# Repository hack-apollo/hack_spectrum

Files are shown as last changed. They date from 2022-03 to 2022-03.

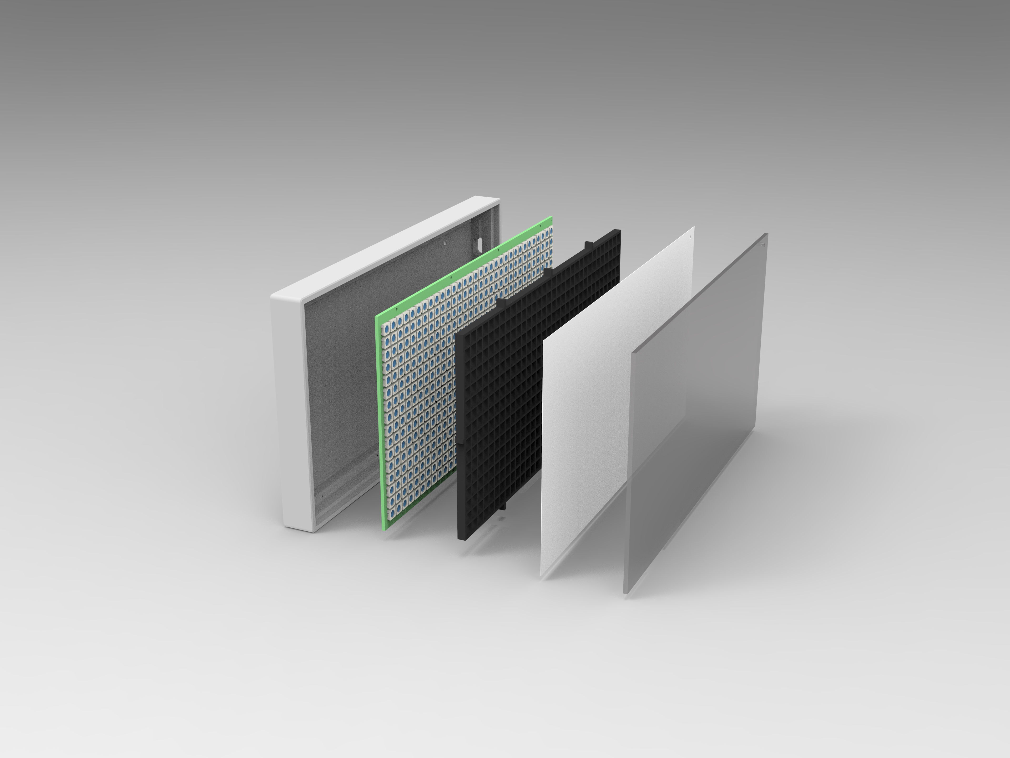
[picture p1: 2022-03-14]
3D/渲染图.jpg

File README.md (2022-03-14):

Hack Labs Audio Spectrum ：https://www.youtube.com/watch?v=lrZFiLHbFRo&lc=Ugw5ZR2V5kvy2mBF6H14AaABAg                                                                                
Author: HACK实验室                                                                                     
YouTube ID: HACK实验室, welcome to subscribe https://www.youtube.com/channel/UCxFY1FcIYK9d7riTvIh6eiA                                                         
Hack Audio Spectrum is a free download and may be used, modified, evaluated and
distributed without charge provided the user adheres to version three of the GNU
General Public License (GPL) and does not remove the copyright notice or this
text.  The GPL V3 text is available on the gnu.org web site
作者：HACK实验室                                                                                        
B站ID：HACK实验室  欢迎订阅 https://space.bilibili.com/395145107                                                                            
微信公众号：HACK实验室，开源资料唯一发布点，定期分享开源硬件以及有价值的技术文章，欢迎关注.

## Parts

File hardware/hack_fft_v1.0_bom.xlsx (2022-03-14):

编号 | 名称 | 值 | 封装 | 数量 | 备注
R1,R4,R5 |  | 100Ω | 0603_R | 3
R2,R3,R10,R11 |  | 5.1KΩ | 0603_R | 4
R6,R7,R8 |  | 10KΩ | 0603_R | 3
R9 |  | 100KΩ | 0603_R | 1
C1,C2,C3,C4,C8,C10,C101&C410 | X5R | 1uF/50V | 0603_C | 64
C5,C6,C9 | X7R | 0.1uF/50V | 0603_C | 3
C7 | 钽电容 | 10uF/16V | A型 3216 | 1
D1~D512 | WS2812B-3535 |  |  | 512
D0,DD0 | 肖特基二极管 | 1N5819WS | SOD-323 | 2
Q1 | BC847BS |  | SOT-363 | 1
U1 | ESP32-PICO-D4 |  | QFN-48 | 1
U2 | ICS-43434 |  | LGA-CAV-6 | 1
U3 | CH340C |  | SOP-16 | 1
U4 | SPX3819M5-L-3-3 |  | SOT23-5 | 1
A1 | PRO-OB-440 | 2.4G射频天线
SW1 | 轻触开关 | 高8mm | 4*4*8MM | 1 | 关键字“4*4*8MM”
P1 | USB-Type-C母座 | SMT全贴片式 16P |  | 1 | 关键字“USB3.1 Type-C 母座 SMT全贴片式 16P”
P2 | USB-Type-C母座 | Type-C 6P 立式贴片6.8mm |  | 1 | 关键字“Type-C母座6P 立式贴片6.8mm”
P6 x8 | 圆头自攻螺丝十字 | M1.4*6 |  | 8
如果整理有误还望见谅，可到“HACK实验室”微信公众号私信通知修改，谢谢！

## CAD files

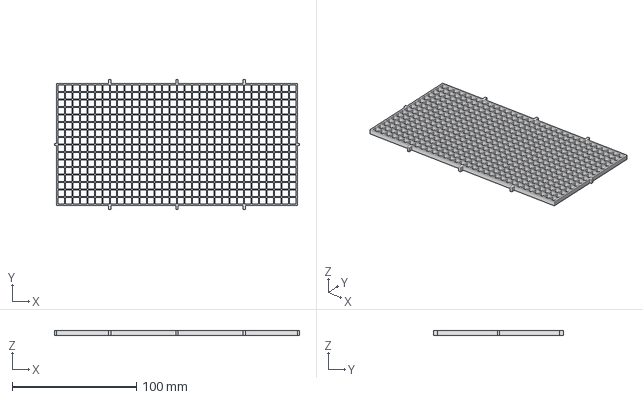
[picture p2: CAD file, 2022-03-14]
3D/stp/栅格.stp
196.8 x 104.8 x 4.00 mm

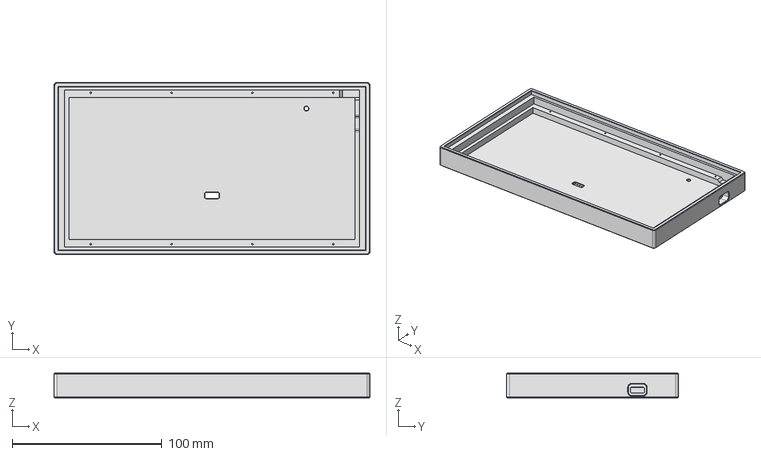
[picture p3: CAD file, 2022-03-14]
3D/stp/壳体.stp
211.0 x 115.0 x 16.5 mm

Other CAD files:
3D/扩散板.dwg
3D/滤光板(厚度2mm).dwg
3D/stl/壳体.stl
3D/stl/栅格.stl

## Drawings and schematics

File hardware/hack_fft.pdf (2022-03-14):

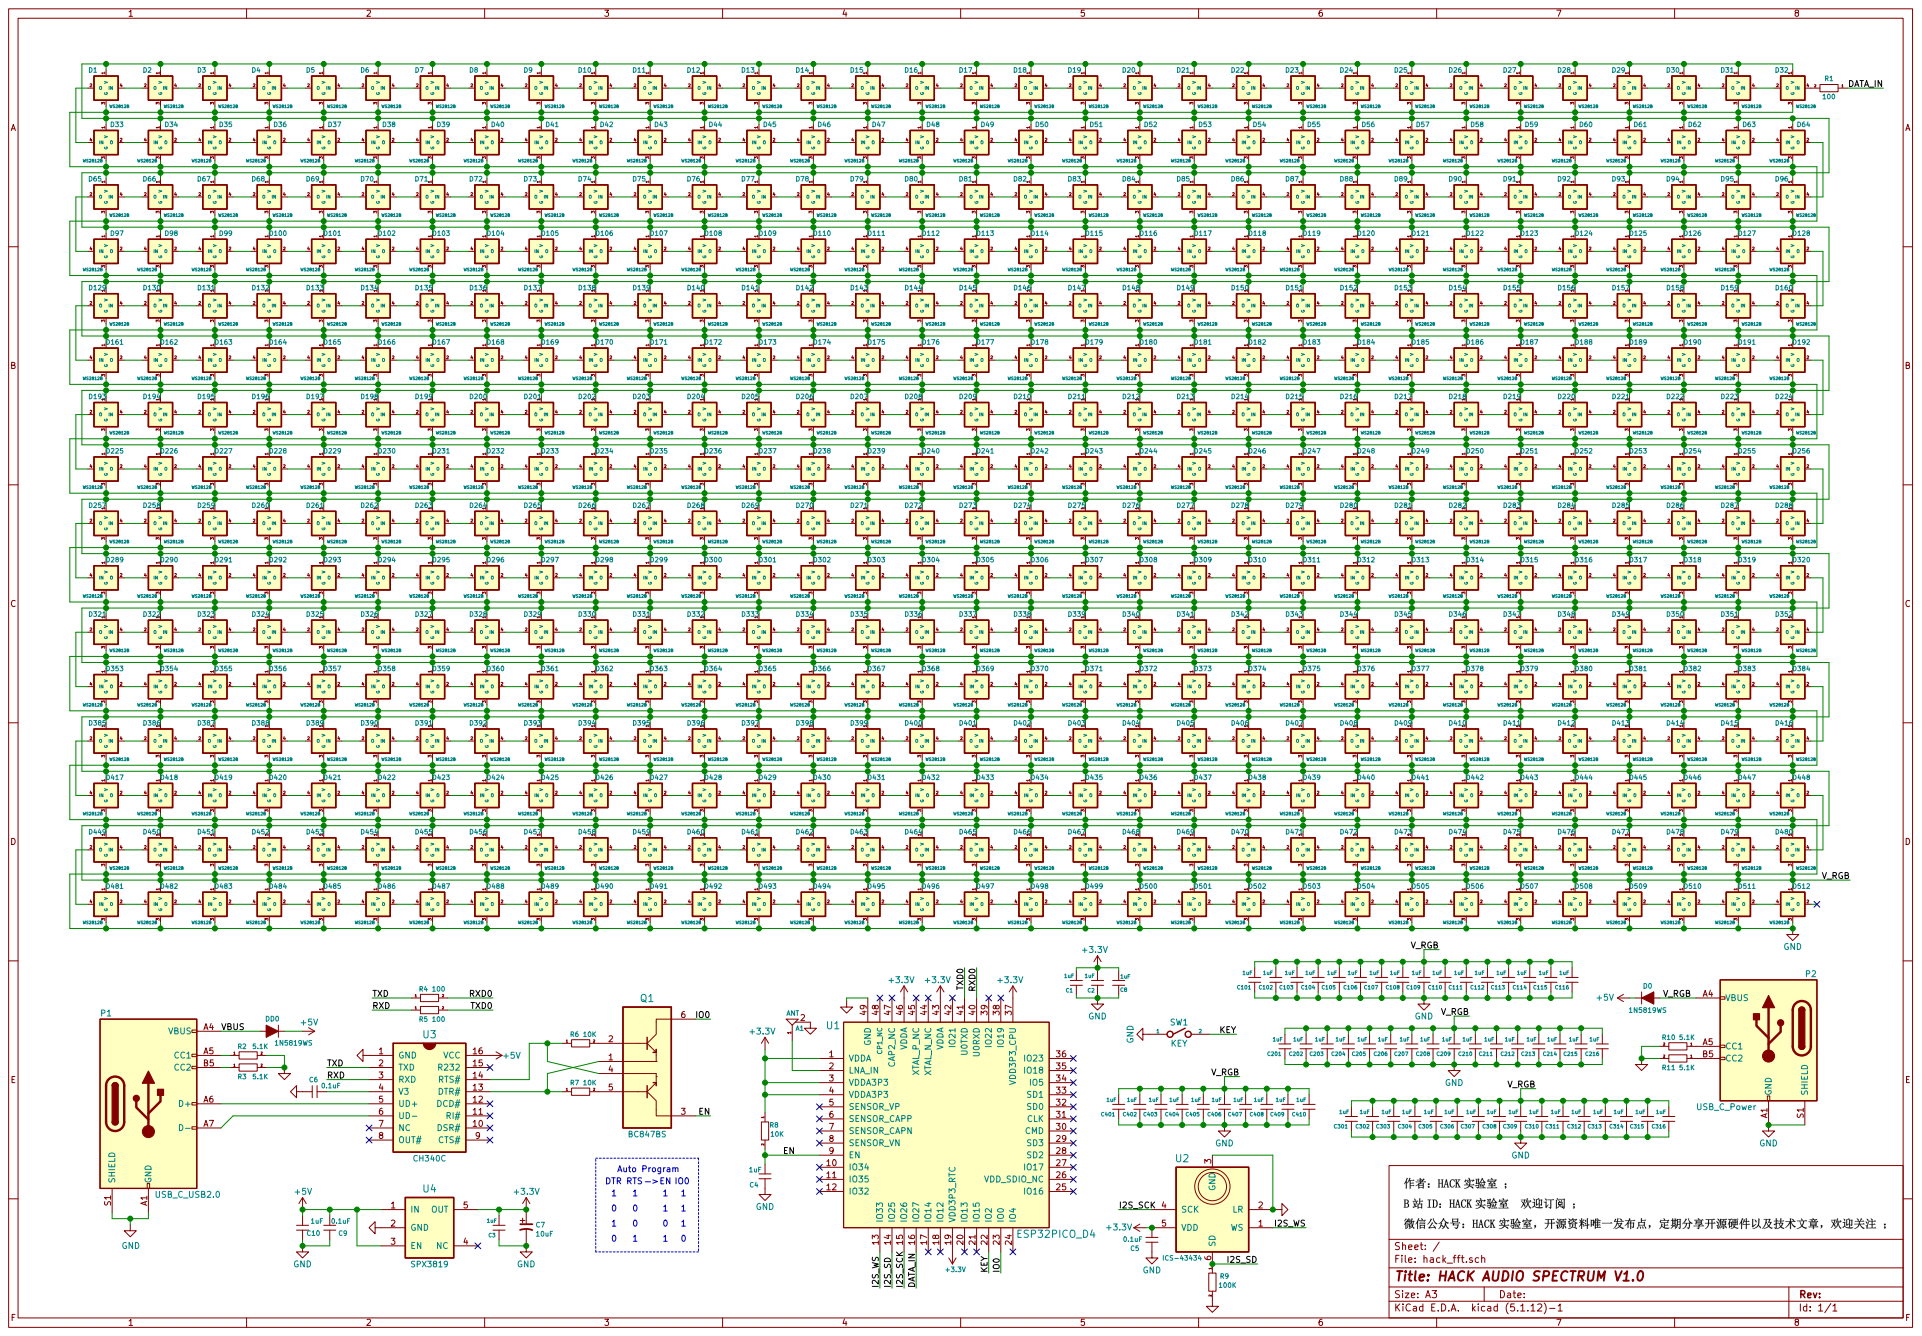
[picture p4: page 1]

File: hack_fft.sch Sheet: /
Id: 1/1 Title: HACK AUDIO SPECTRUM V1.0

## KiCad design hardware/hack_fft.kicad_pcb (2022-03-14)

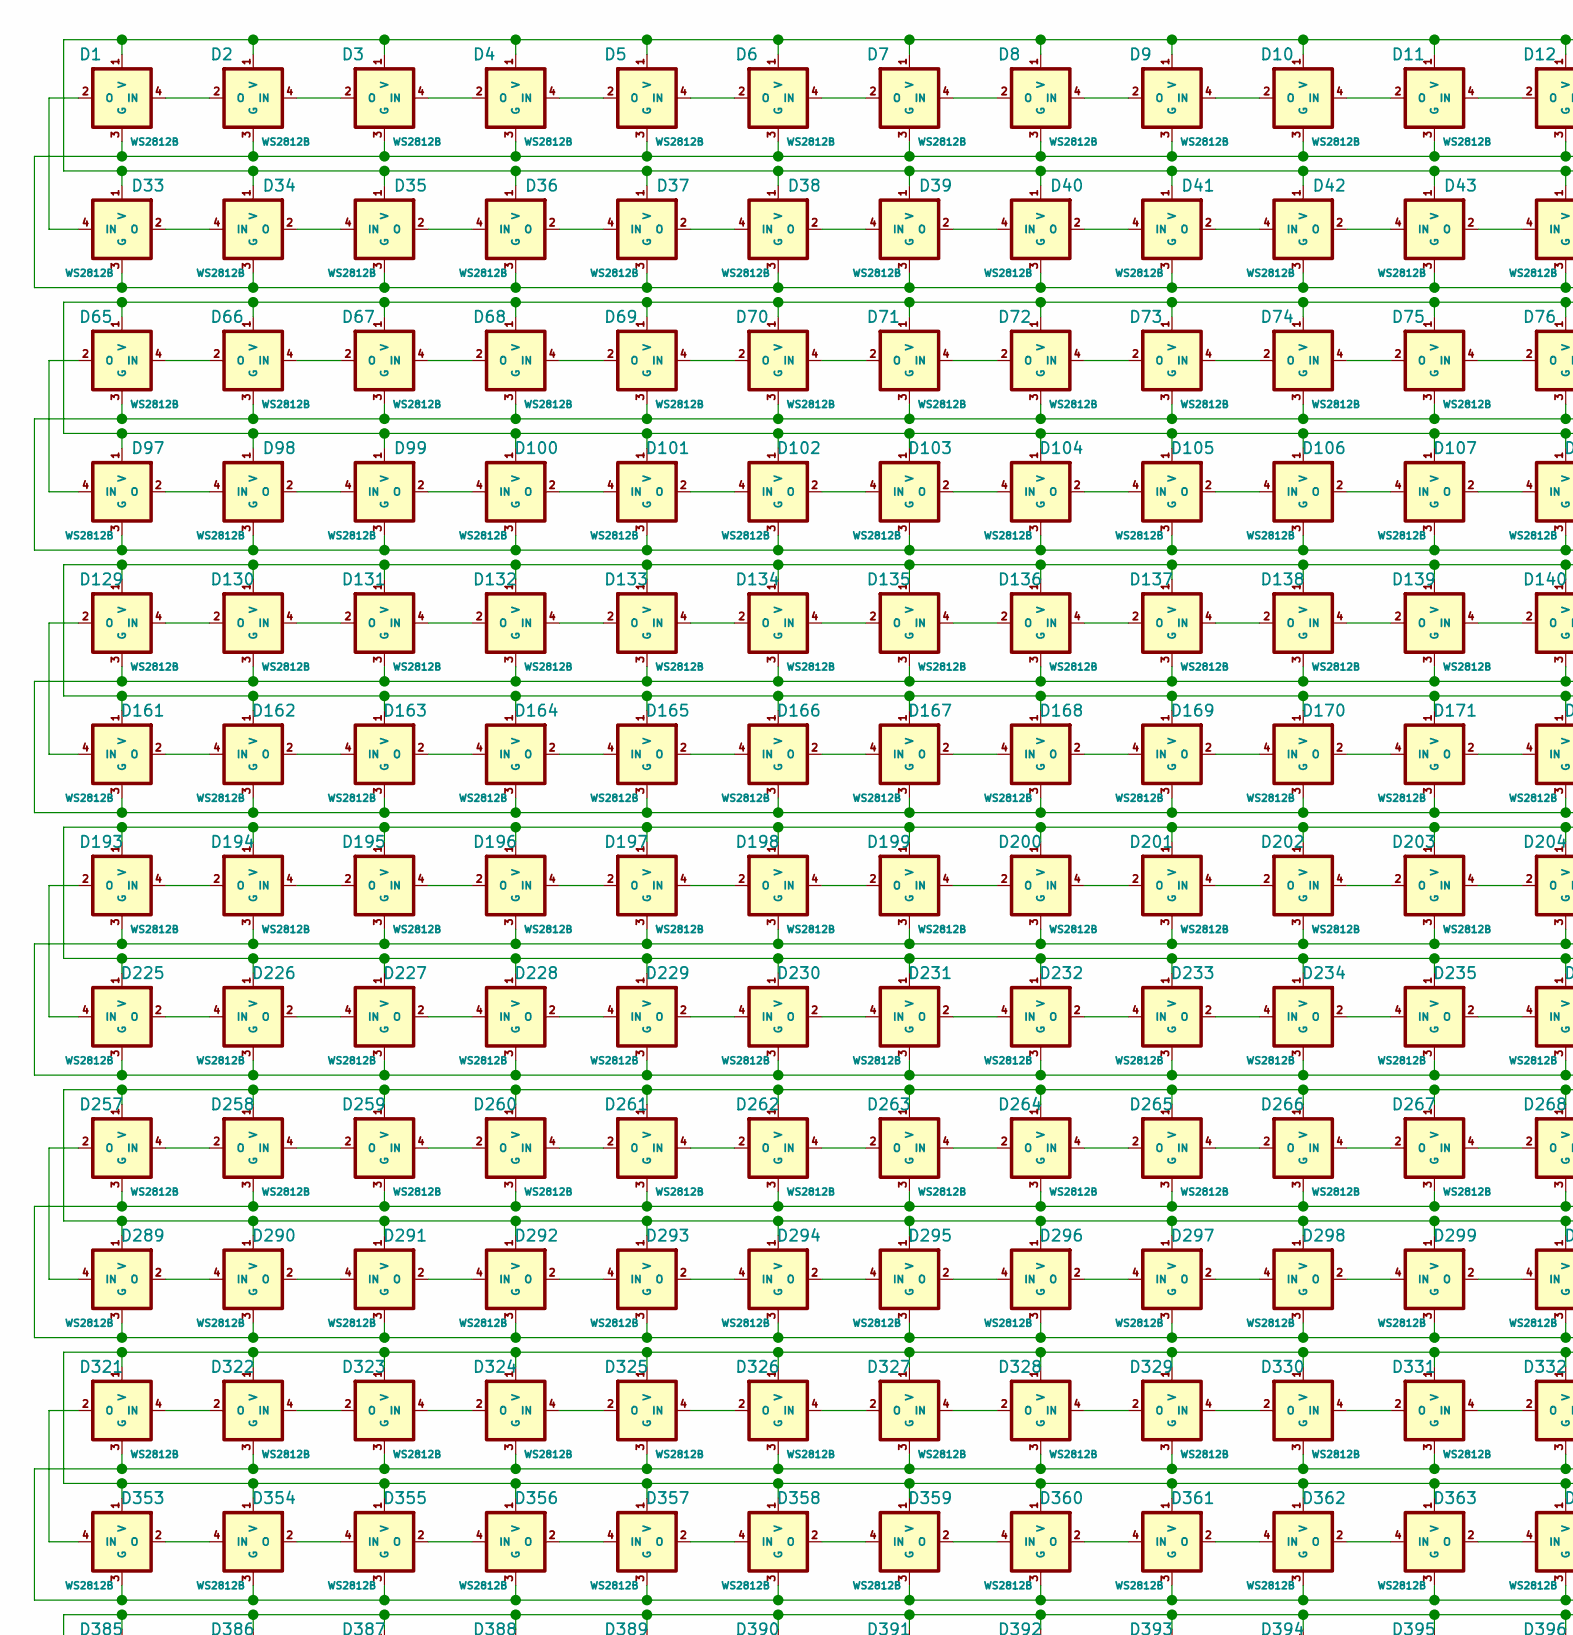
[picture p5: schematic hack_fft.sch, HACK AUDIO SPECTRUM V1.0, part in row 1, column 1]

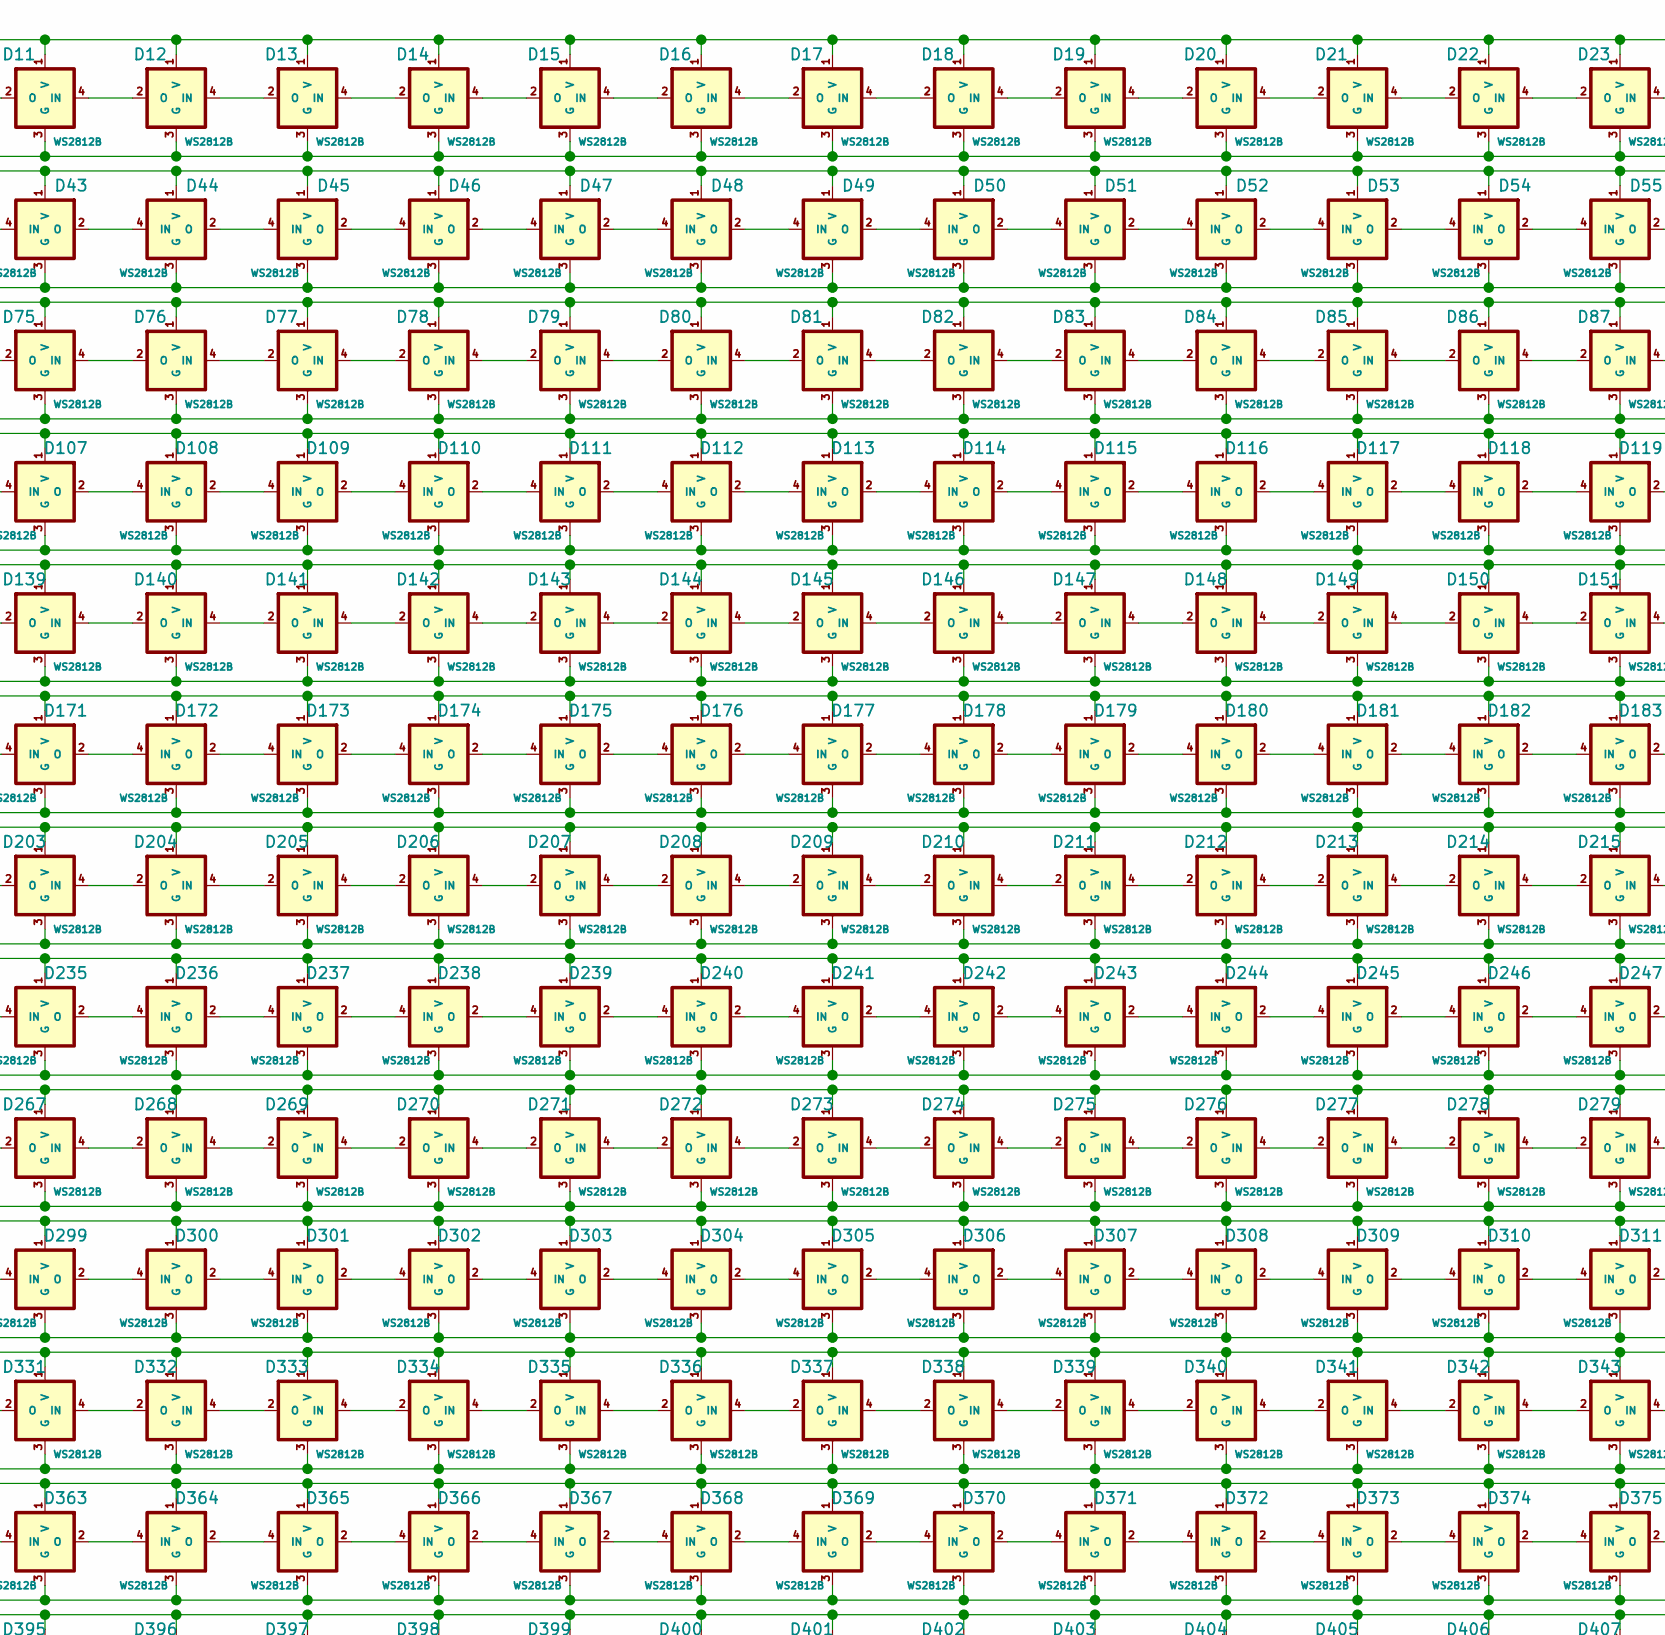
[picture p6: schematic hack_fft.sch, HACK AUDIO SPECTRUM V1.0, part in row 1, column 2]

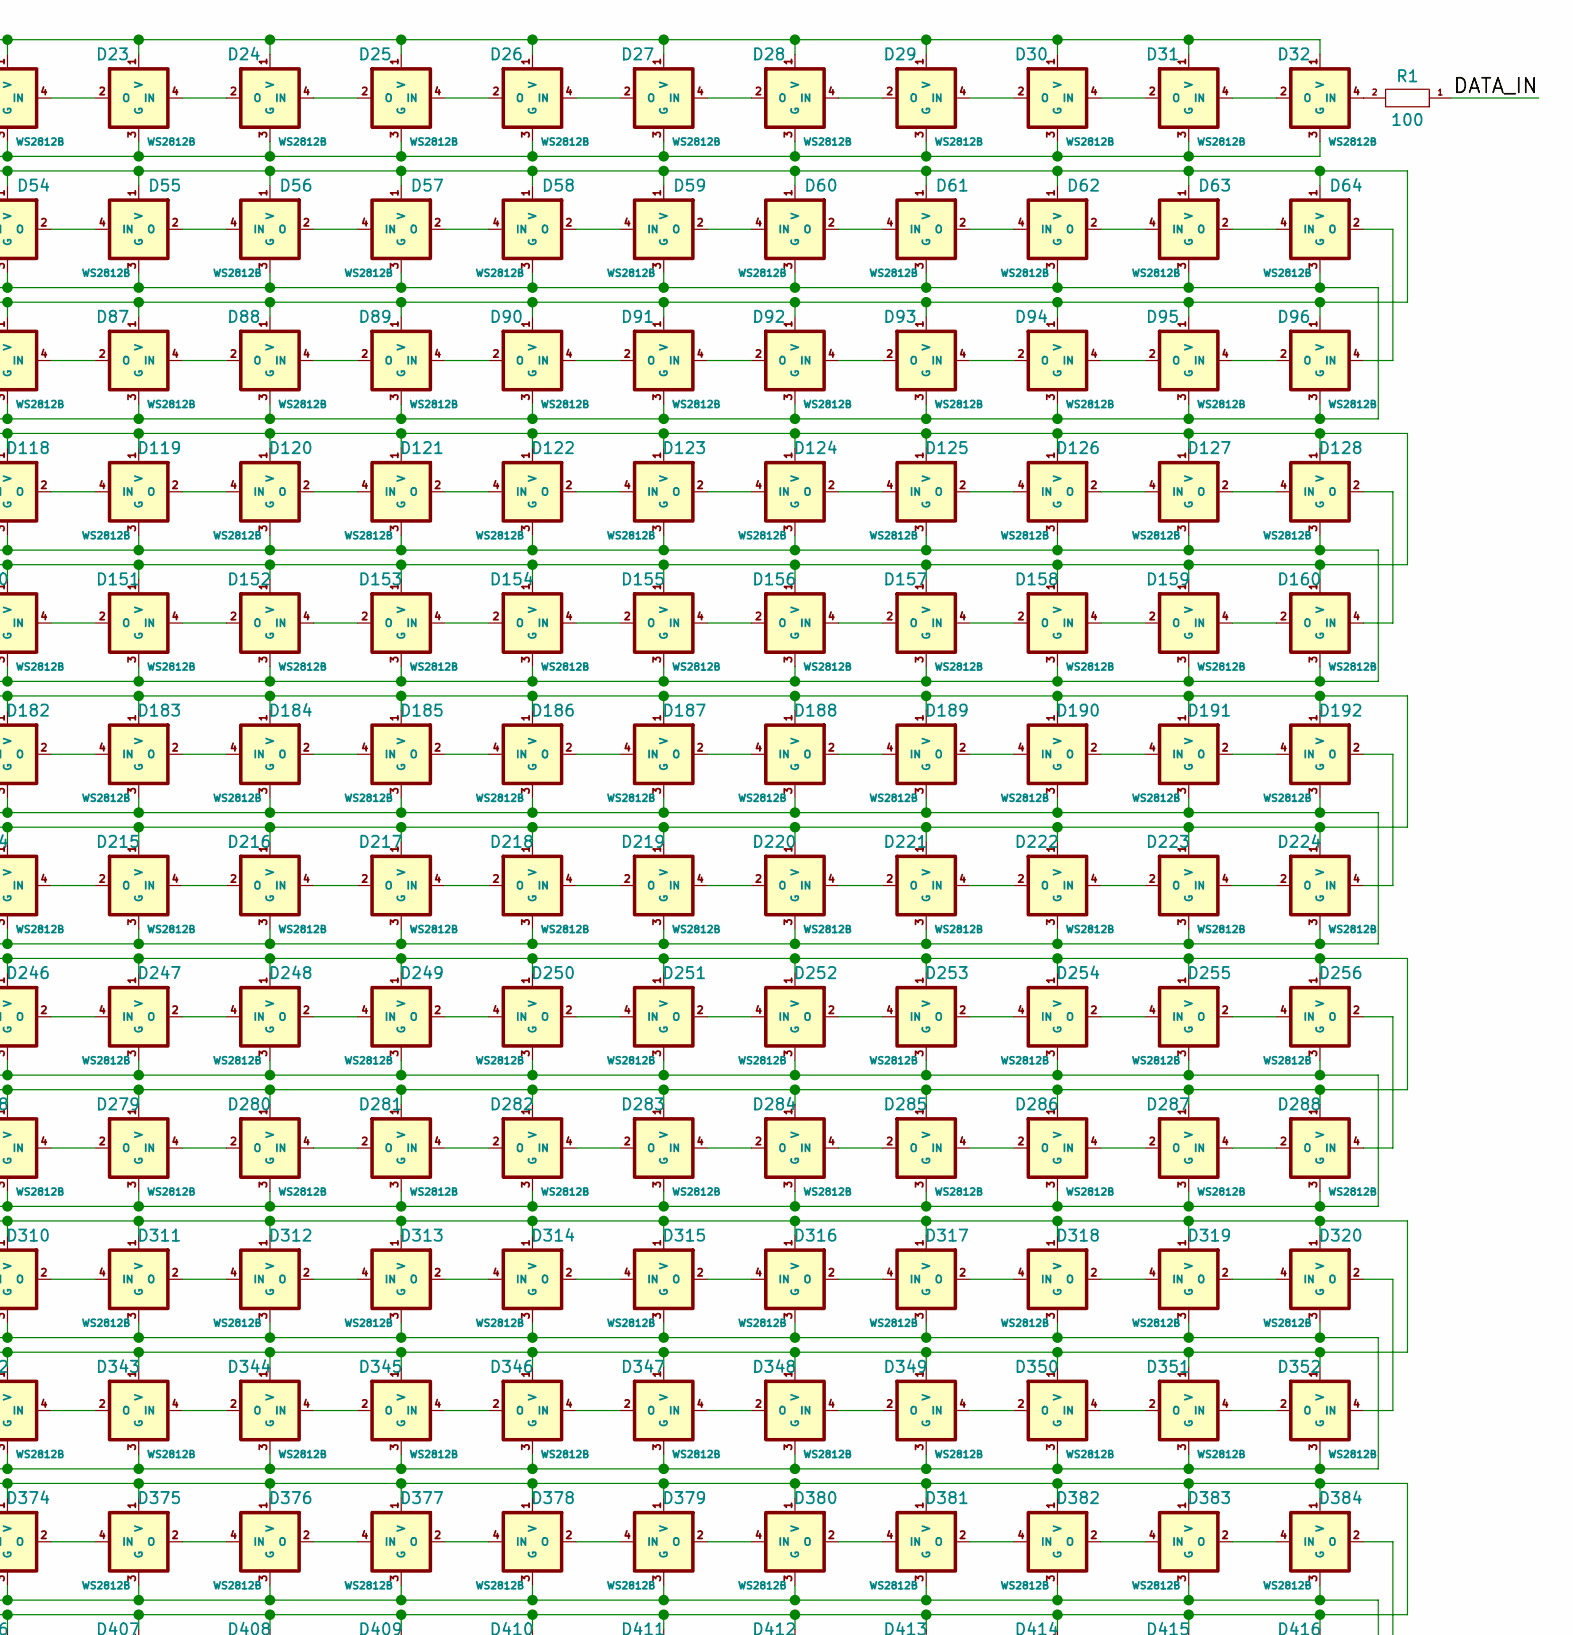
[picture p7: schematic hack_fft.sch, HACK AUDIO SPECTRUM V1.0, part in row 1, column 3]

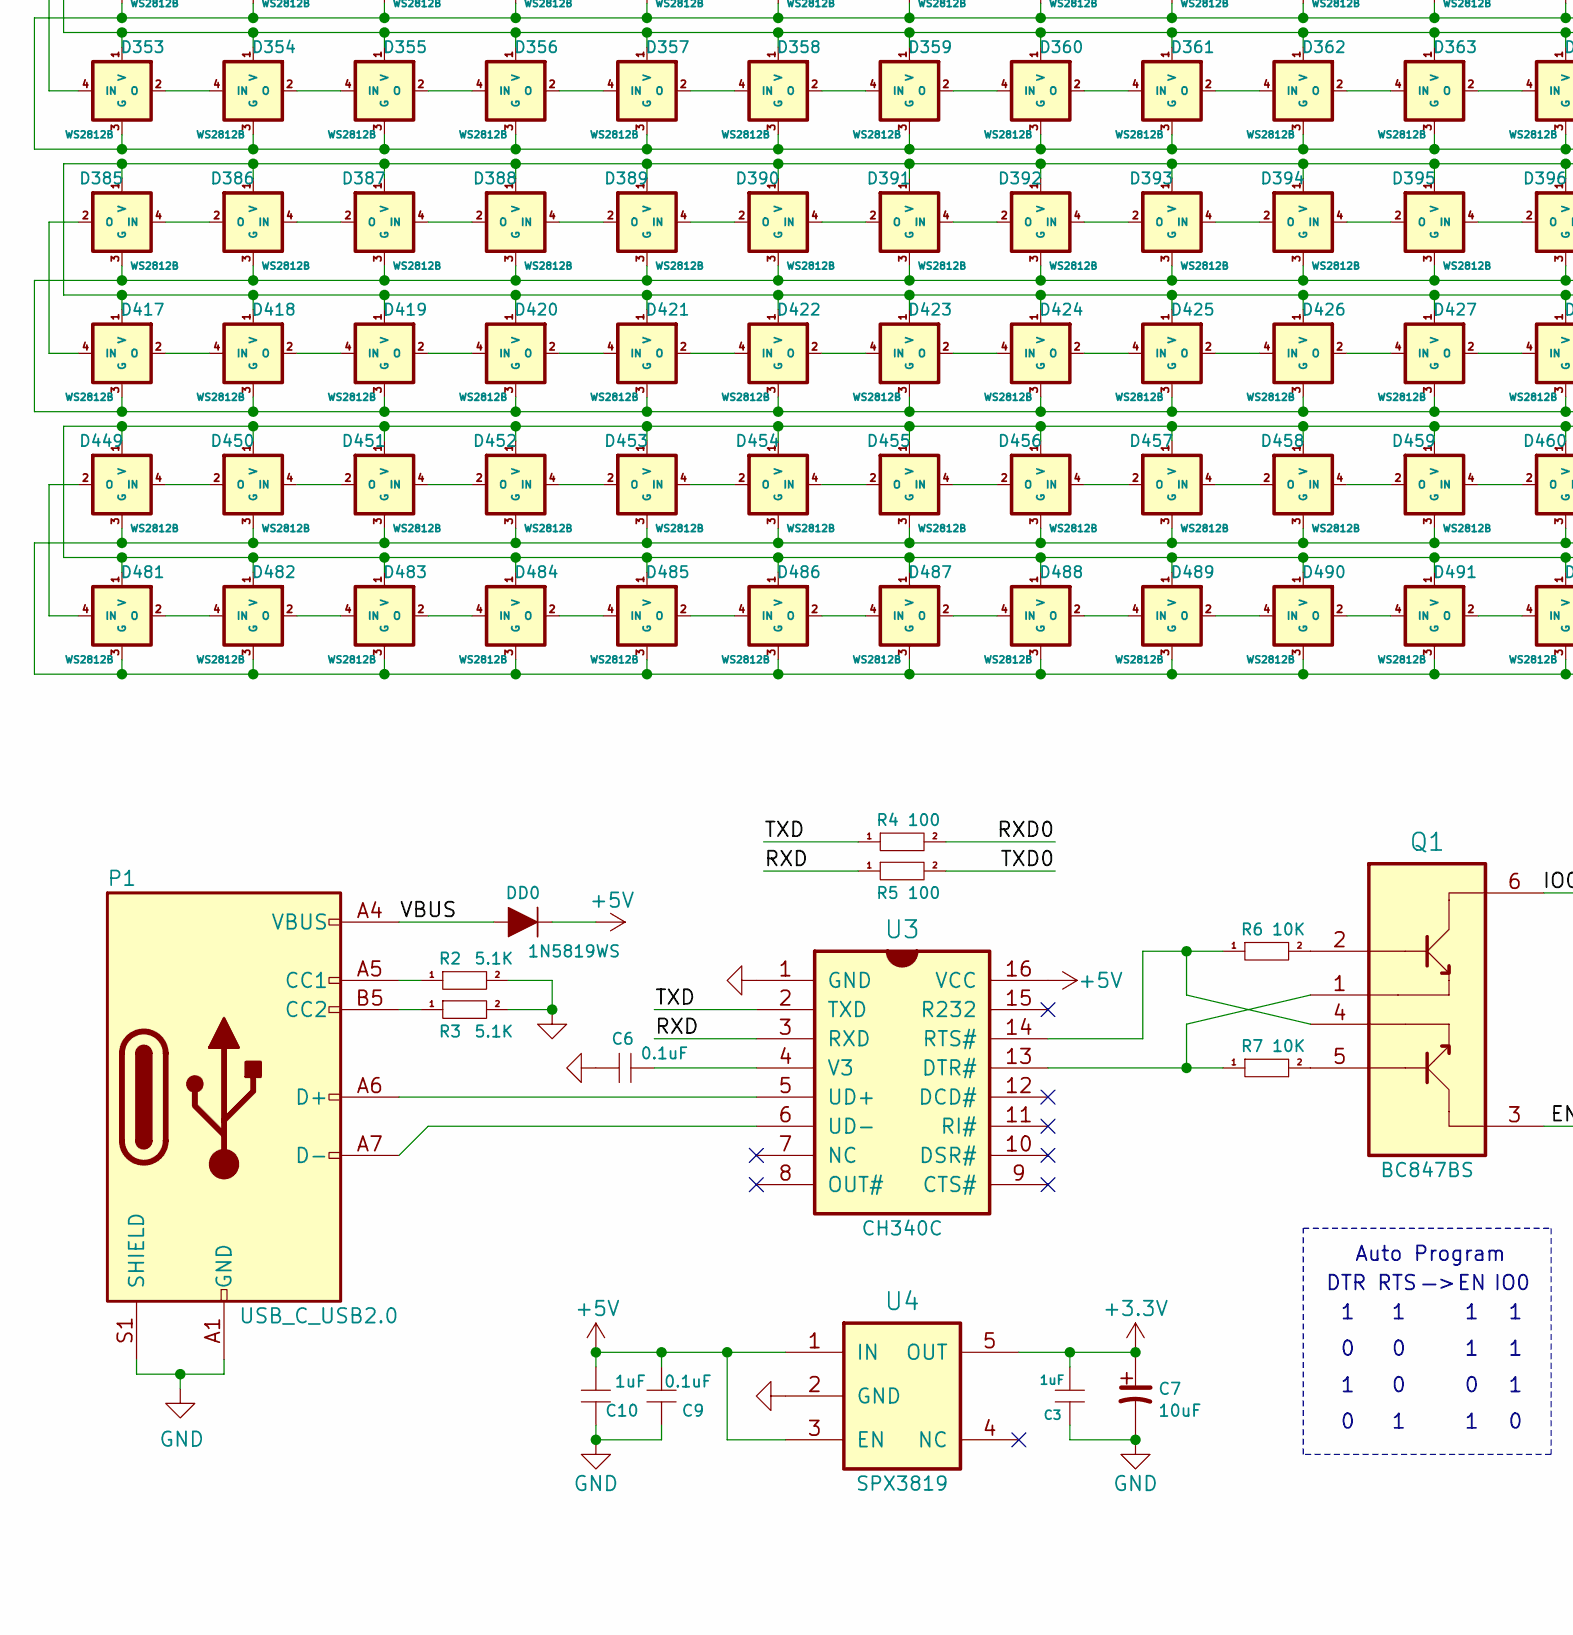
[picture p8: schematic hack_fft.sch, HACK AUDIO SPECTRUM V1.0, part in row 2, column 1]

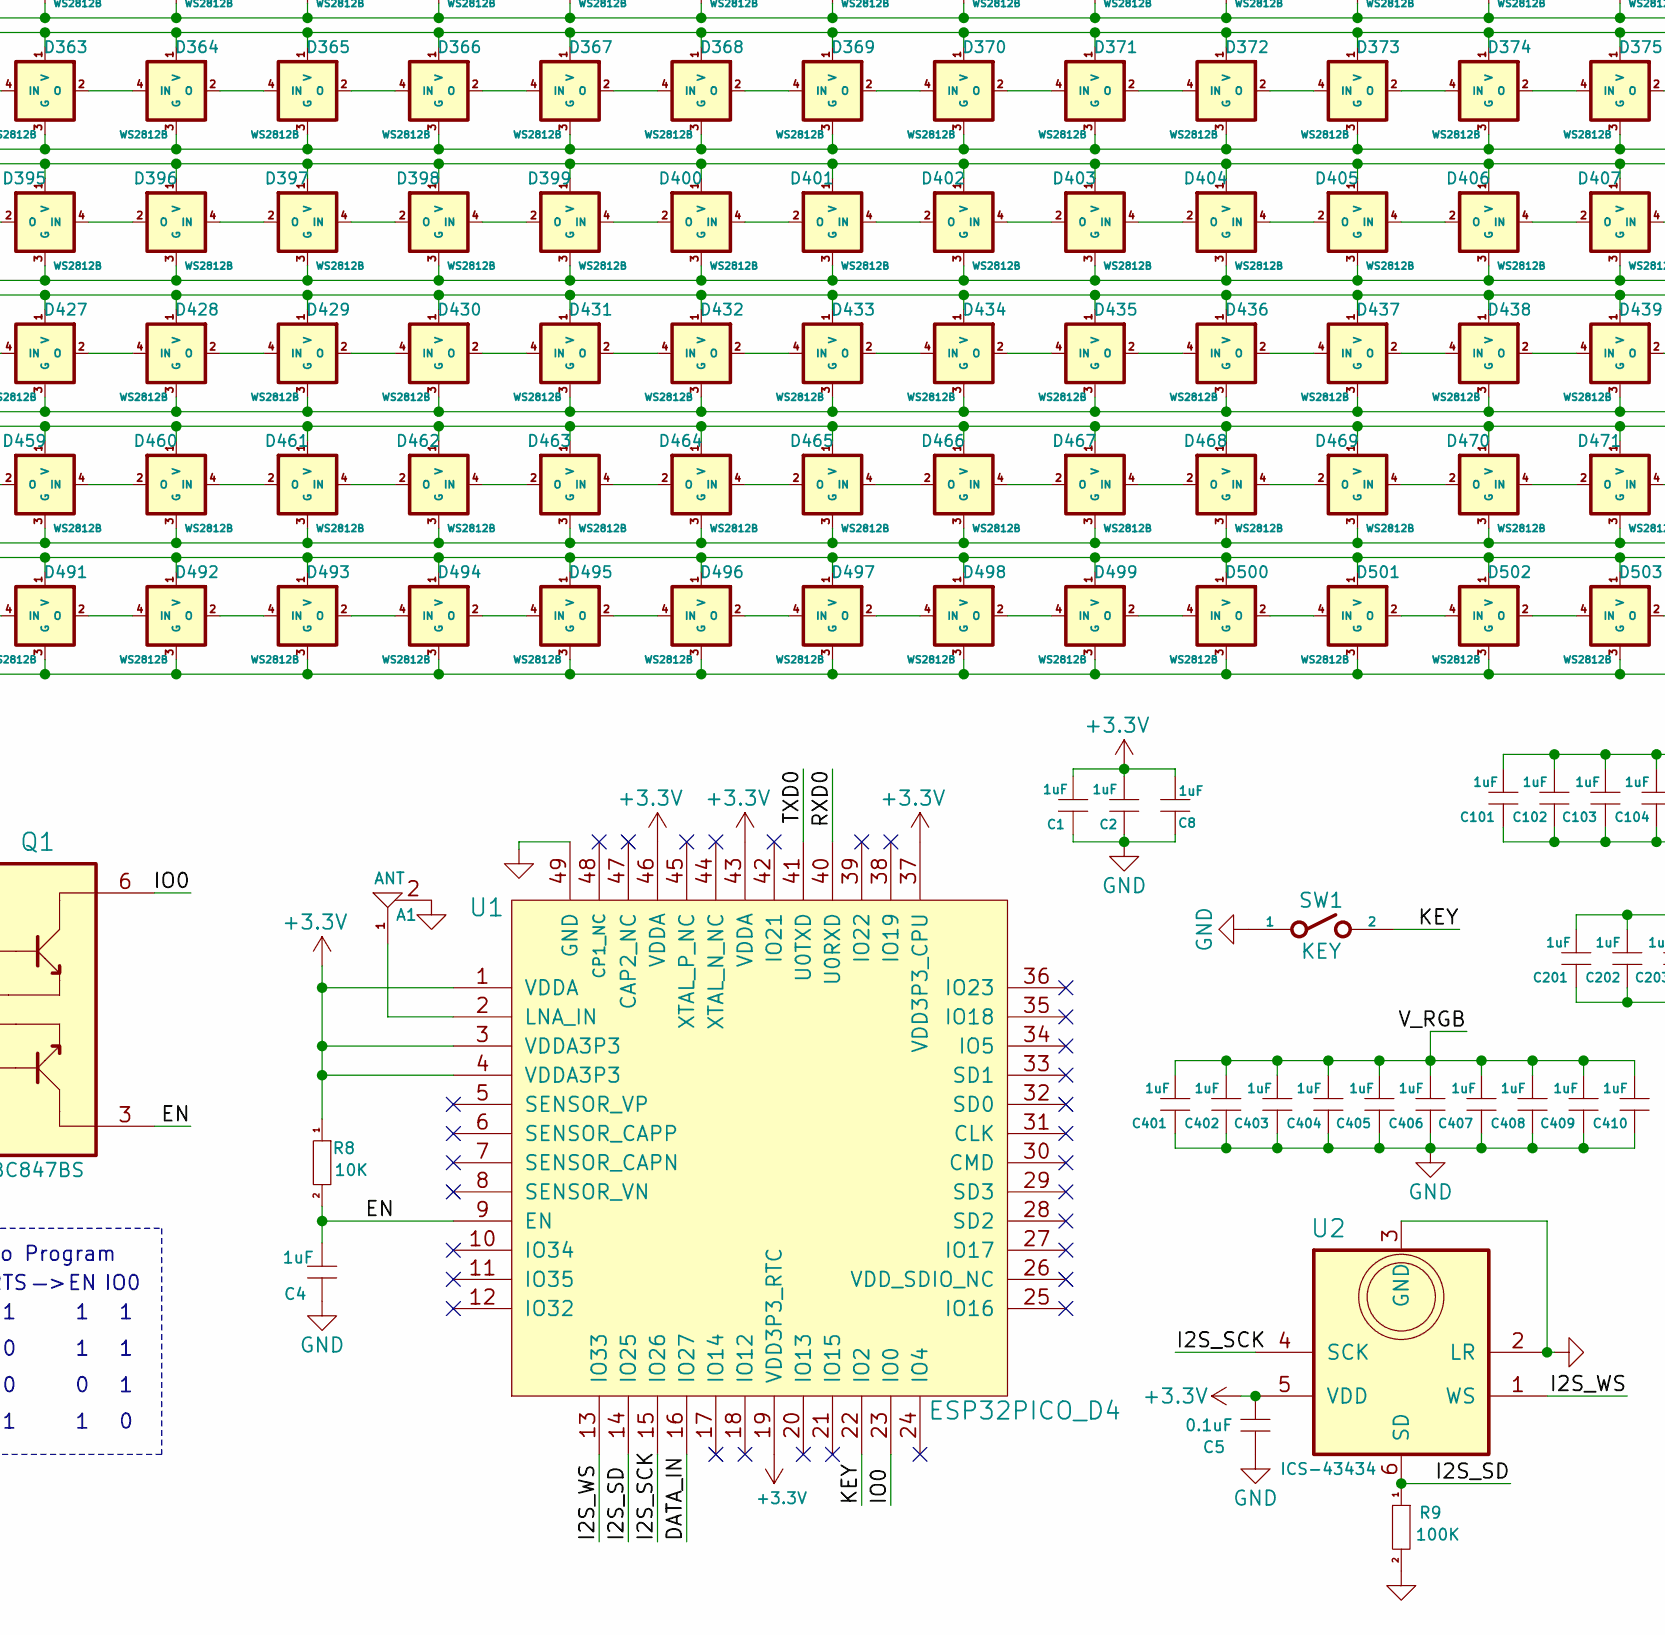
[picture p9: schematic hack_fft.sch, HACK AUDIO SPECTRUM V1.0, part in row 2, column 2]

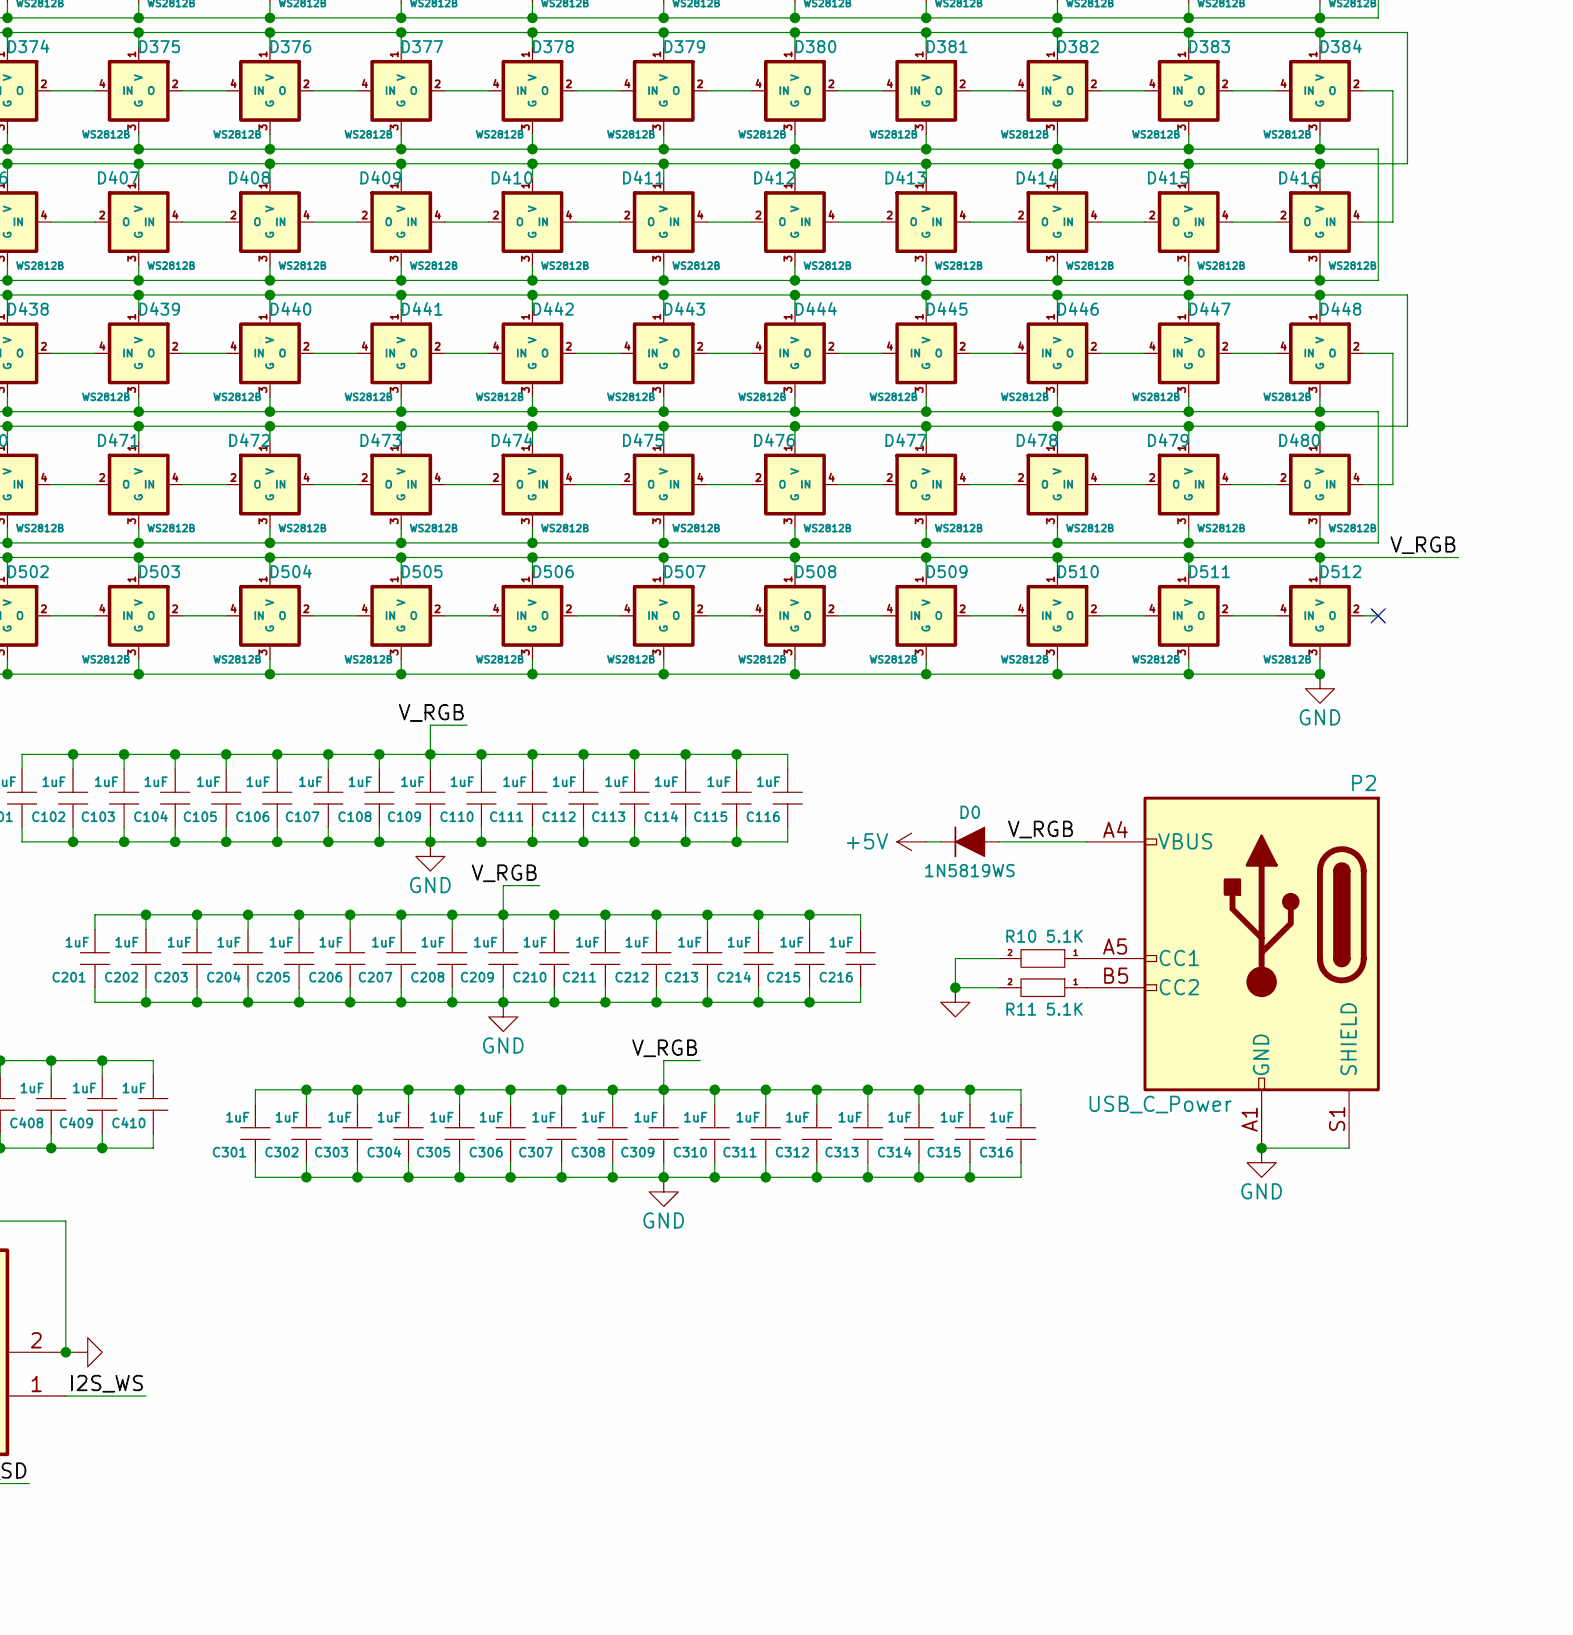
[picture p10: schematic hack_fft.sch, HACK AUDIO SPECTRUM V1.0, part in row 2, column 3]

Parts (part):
A1: ANT; ProAnt_PRO-OB-440
C1, C2, C3, C4, C8, C10, C101, C102, C103, C104, C105, C106, C107, C108, C109, C110, C111, C112, C113, C114, C115, C116, C201, C202, C203, C204, C205, C206, C207, C208, C209, C210, C211, C212, C213, C214, C215, C216, C301, C302, C303, C304, C305, C306, C307, C308, C309, C310, C311, C312, C313, C314, C315, C316, C401, C402, C403, C404, C405, C406, C407, C408, C409, C410: 1uF; 0603_C
C5, C6, C9: 0.1uF; 0603_C
C7: 10uF; TantalC_SizeT_3528
D0: 1N5819WS; F_1206
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

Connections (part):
+3V3: C1.2, C2.2, C3.2, C5.2, C7.1, C8.2, R8.1, U1.1 (VDDA), U1.3 (VDDA3P3), U1.4 (VDDA3P3), U1.19 (VDD3P3_RTC), U1.37 (VDD3P3_CPU), U1.43 (VDDA), U1.46 (VDDA), U2.5 (VDD), U4.5 (OUT)
+5V: C9.2, C10.2, D0.2 (K), DD0.2 (K), U3.16 (VCC), U4.1 (IN), U4.3 (EN)
/DATA_IN: R1.1, U1.16 (IO27)
/EN: C4.2, Q1.3, R8.2, U1.9 (EN)
/I2S_SCK: U1.15 (IO26), U2.4 (SCK)
/I2S_SD: R9.1, U1.14 (IO25), U2.6 (SD)
/I2S_WS: U1.13 (IO33), U2.1 (WS)
/IO0: Q1.6, U1.23 (IO0)
/KEY: SW1.2, U1.22 (IO2)
/RXD: R5.1, U3.3 (RXD)
/RXD0: R4.2, U1.40 (U0RXD)
/TXD: R4.1, U3.2 (TXD)
/TXD0: R5.2, U1.41 (U0TXD)
/VBUS: DD0.1 (A), P1.A4 (VBUS), P1.A9 (VBUS), P1.B4 (VBUS), P1.B9 (VBUS)
/V_RGB: C101.2, C102.2, C103.2, C104.2, C105.2, C106.2, C107.2, C108.2, C109.2, C110.2, C111.2, C112.2, C113.2, C114.2, C115.2, C116.2, C201.2, C202.2, C203.2, C204.2, C205.2, C206.2, C207.2, C208.2, C209.2, C210.2, C211.2, C212.2, C213.2, C214.2, C215.2, C216.2, C301.2, C302.2, C303.2, C304.2, C305.2, C306.2, C307.2, C308.2, C309.2, C310.2, C311.2, C312.2, C313.2, C314.2, C315.2, C316.2, C401.2, C402.2, C403.2, C404.2, C405.2, C406.2, C407.2, C408.2, C409.2, C410.2, D0.1 (A), D1.1 (V), D2.1 (V), D3.1 (V), D4.1 (V), D5.1 (V), D6.1 (V), D7.1 (V), D8.1 (V), D9.1 (V), D10.1 (V), D11.1 (V), D12.1 (V), D13.1 (V), D14.1 (V), D15.1 (V), D16.1 (V), D17.1 (V), D18.1 (V), D19.1 (V), D20.1 (V), D21.1 (V)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; also elsewhere on the board
GND: A1.2, C1.1, C2.1, C3.1, C4.1, C5.1, C6.1, C7.2, C8.1, C9.1, C10.1, C101.1, C102.1, C103.1, C104.1, C105.1, C106.1, C107.1, C108.1, C109.1, C110.1, C111.1, C112.1, C113.1, C114.1, C115.1, C116.1, C201.1, C202.1, C203.1, C204.1, C205.1, C206.1, C207.1, C208.1, C209.1, C210.1, C211.1, C212.1, C213.1, C214.1, C215.1, C216.1, C301.1, C302.1, C303.1, C304.1, C305.1, C306.1, C307.1, C308.1, C309.1, C310.1, C311.1, C312.1, C313.1, C314.1, C315.1, C316.1, C401.1, C402.1, C403.1, C404.1, C405.1, C406.1, C407.1, C408.1, C409.1, C410.1, D1.3 (G), D2.3 (G), D3.3 (G), D4.3 (G), D5.3 (G), D6.3 (G), D7.3 (G), D8.3 (G), D9.3 (G), D10.3 (G), D11.3 (G)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; also elsewhere on the board
unnamed: A1.1, U1.2 (LNA_IN)
unnamed: C6.2, U3.4 (V3)
unnamed: D1.2 (O), D33.4 (IN)
unnamed: D1.4 (IN), D2.2 (O)
unnamed: D2.4 (IN), D3.2 (O)
unnamed: D3.4 (IN), D4.2 (O)
unnamed: D4.4 (IN), D5.2 (O)
unnamed: D5.4 (IN), D6.2 (O)
unnamed: D6.4 (IN), D7.2 (O)
unnamed: D7.4 (IN), D8.2 (O)
unnamed: D8.4 (IN), D9.2 (O)
unnamed: D9.4 (IN), D10.2 (O)
unnamed: D10.4 (IN), D11.2 (O)
unnamed: D11.4 (IN), D12.2 (O)
unnamed: D12.4 (IN), D13.2 (O)
unnamed: D13.4 (IN), D14.2 (O)
unnamed: D14.4 (IN), D15.2 (O)
unnamed: D15.4 (IN), D16.2 (O)
unnamed: D16.4 (IN), D17.2 (O)
unnamed: D17.4 (IN), D18.2 (O)
unnamed: D18.4 (IN), D19.2 (O)
unnamed: D19.4 (IN), D20.2 (O)
unnamed: D20.4 (IN), D21.2 (O)
unnamed: D21.4 (IN), D22.2 (O)
unnamed: D22.4 (IN), D23.2 (O)
unnamed: D23.4 (IN), D24.2 (O)
unnamed: D24.4 (IN), D25.2 (O)
unnamed: D25.4 (IN), D26.2 (O)
unnamed: D26.4 (IN), D27.2 (O)
unnamed: D27.4 (IN), D28.2 (O)
unnamed: D28.4 (IN), D29.2 (O)
unnamed: D29.4 (IN), D30.2 (O)
unnamed: D30.4 (IN), D31.2 (O)
unnamed: D31.4 (IN), D32.2 (O)
unnamed: D32.4 (IN), R1.2
unnamed: D33.2 (O), D34.4 (IN)
unnamed: D34.2 (O), D35.4 (IN)
unnamed: D35.2 (O), D36.4 (IN)
unnamed: D36.2 (O), D37.4 (IN)
unnamed: D37.2 (O), D38.4 (IN)
unnamed: D38.2 (O), D39.4 (IN)
unnamed: D39.2 (O), D40.4 (IN)
unnamed 58: D40.2 (O), D41.4 (IN); also elsewhere on the board
unnamed 59: D41.2 (O), D42.4 (IN); also elsewhere on the board
unnamed: D42.2 (O), D43.4 (IN)
unnamed: D43.2 (O), D44.4 (IN)
unnamed: D44.2 (O), D45.4 (IN)
unnamed: D45.2 (O), D46.4 (IN)
unnamed: D46.2 (O), D47.4 (IN)
unnamed: D47.2 (O), D48.4 (IN)
unnamed: D48.2 (O), D49.4 (IN)
unnamed: D49.2 (O), D50.4 (IN)
unnamed: D50.2 (O), D51.4 (IN)
unnamed: D51.2 (O), D52.4 (IN)
unnamed: D52.2 (O), D53.4 (IN)
unnamed: D53.2 (O), D54.4 (IN)
unnamed: D54.2 (O), D55.4 (IN)
unnamed: D55.2 (O), D56.4 (IN)
unnamed: D56.2 (O), D57.4 (IN)
unnamed: D57.2 (O), D58.4 (IN)
unnamed: D58.2 (O), D59.4 (IN)
unnamed: D59.2 (O), D60.4 (IN)
unnamed: D60.2 (O), D61.4 (IN)
unnamed: D61.2 (O), D62.4 (IN)
unnamed: D62.2 (O), D63.4 (IN)
unnamed: D63.2 (O), D64.4 (IN)
unnamed: D64.2 (O), D96.4 (IN)
unnamed: D65.2 (O), D97.4 (IN)
unnamed: D65.4 (IN), D66.2 (O)
unnamed: D66.4 (IN), D67.2 (O)
unnamed: D67.4 (IN), D68.2 (O)
unnamed: D68.4 (IN), D69.2 (O)
unnamed: D69.4 (IN), D70.2 (O)
unnamed: D70.4 (IN), D71.2 (O)
unnamed: D71.4 (IN), D72.2 (O)
unnamed: D72.4 (IN), D73.2 (O)
unnamed: D73.4 (IN), D74.2 (O)
unnamed: D74.4 (IN), D75.2 (O)
unnamed: D75.4 (IN), D76.2 (O)
unnamed: D76.4 (IN), D77.2 (O)
unnamed: D77.4 (IN), D78.2 (O)
unnamed: D78.4 (IN), D79.2 (O)
unnamed: D79.4 (IN), D80.2 (O)
unnamed: D80.4 (IN), D81.2 (O)
unnamed: D81.4 (IN), D82.2 (O)
unnamed: D82.4 (IN), D83.2 (O)
unnamed: D83.4 (IN), D84.2 (O)
unnamed: D84.4 (IN), D85.2 (O)
unnamed: D85.4 (IN), D86.2 (O)
unnamed: D86.4 (IN), D87.2 (O)
unnamed: D87.4 (IN), D88.2 (O)
unnamed: D88.4 (IN), D89.2 (O)
unnamed: D89.4 (IN), D90.2 (O)
unnamed: D90.4 (IN), D91.2 (O)
unnamed: D91.4 (IN), D92.2 (O)
unnamed: D92.4 (IN), D93.2 (O)
unnamed: D93.4 (IN), D94.2 (O)
unnamed: D94.4 (IN), D95.2 (O)
unnamed: D95.4 (IN), D96.2 (O)
unnamed: D97.2 (O), D98.4 (IN)
unnamed: D98.2 (O), D99.4 (IN)
unnamed: D100.2 (O), D101.4 (IN)
unnamed: D99.2 (O), D100.4 (IN)
unnamed: D101.2 (O), D102.4 (IN)
unnamed: D102.2 (O), D103.4 (IN)
unnamed: D103.2 (O), D104.4 (IN)
unnamed: D104.2 (O), D105.4 (IN)
unnamed: D105.2 (O), D106.4 (IN)
unnamed: D106.2 (O), D107.4 (IN)
unnamed: D107.2 (O), D108.4 (IN)
unnamed: D108.2 (O), D109.4 (IN)
unnamed: D109.2 (O), D110.4 (IN)
unnamed: D110.2 (O), D111.4 (IN)
unnamed: D111.2 (O), D112.4 (IN)
unnamed: D112.2 (O), D113.4 (IN)
unnamed: D113.2 (O), D114.4 (IN)
unnamed: D114.2 (O), D115.4 (IN)
unnamed: D115.2 (O), D116.4 (IN)
unnamed: D116.2 (O), D117.4 (IN)
unnamed: D117.2 (O), D118.4 (IN)
unnamed: D118.2 (O), D119.4 (IN)
unnamed: D119.2 (O), D120.4 (IN)
unnamed: D120.2 (O), D121.4 (IN)
unnamed: D121.2 (O), D122.4 (IN)
unnamed: D122.2 (O), D123.4 (IN)
unnamed: D123.2 (O), D124.4 (IN)
unnamed: D124.2 (O), D125.4 (IN)
unnamed: D125.2 (O), D126.4 (IN)
unnamed: D126.2 (O), D127.4 (IN)
unnamed: D127.2 (O), D128.4 (IN)
unnamed: D128.2 (O), D160.4 (IN)
unnamed: D129.2 (O), D161.4 (IN)
unnamed: D129.4 (IN), D130.2 (O)
unnamed: D130.4 (IN), D131.2 (O)
unnamed: D131.4 (IN), D132.2 (O)
unnamed: D132.4 (IN), D133.2 (O)
unnamed: D133.4 (IN), D134.2 (O)
unnamed: D134.4 (IN), D135.2 (O)
unnamed: D135.4 (IN), D136.2 (O)
unnamed: D136.4 (IN), D137.2 (O)
unnamed: D137.4 (IN), D138.2 (O)
unnamed: D138.4 (IN), D139.2 (O)
unnamed: D139.4 (IN), D140.2 (O)
unnamed: D140.4 (IN), D141.2 (O)
unnamed: D141.4 (IN), D142.2 (O)
unnamed: D142.4 (IN), D143.2 (O)
unnamed: D143.4 (IN), D144.2 (O)
unnamed: D144.4 (IN), D145.2 (O)
unnamed: D145.4 (IN), D146.2 (O)
unnamed: D146.4 (IN), D147.2 (O)
unnamed: D147.4 (IN), D148.2 (O)
unnamed: D148.4 (IN), D149.2 (O)
unnamed: D149.4 (IN), D150.2 (O)
unnamed: D150.4 (IN), D151.2 (O)
unnamed: D151.4 (IN), D152.2 (O)
unnamed: D152.4 (IN), D153.2 (O)
unnamed: D153.4 (IN), D154.2 (O)
unnamed: D154.4 (IN), D155.2 (O)
unnamed: D155.4 (IN), D156.2 (O)
unnamed: D156.4 (IN), D157.2 (O)
unnamed: D157.4 (IN), D158.2 (O)
unnamed: D158.4 (IN), D159.2 (O)
unnamed: D159.4 (IN), D160.2 (O)
unnamed: D161.2 (O), D162.4 (IN)
unnamed: D162.2 (O), D163.4 (IN)
unnamed: D163.2 (O), D164.4 (IN)
unnamed: D164.2 (O), D165.4 (IN)
unnamed: D165.2 (O), D166.4 (IN)
unnamed: D166.2 (O), D167.4 (IN)
unnamed: D167.2 (O), D168.4 (IN)
unnamed: D168.2 (O), D169.4 (IN)
unnamed: D169.2 (O), D170.4 (IN)
unnamed: D170.2 (O), D171.4 (IN)
unnamed: D171.2 (O), D172.4 (IN)
unnamed: D172.2 (O), D173.4 (IN)
unnamed: D173.2 (O), D174.4 (IN)
unnamed: D174.2 (O), D175.4 (IN)
unnamed: D175.2 (O), D176.4 (IN)
unnamed: D176.2 (O), D177.4 (IN)
unnamed: D177.2 (O), D178.4 (IN)
unnamed: D178.2 (O), D179.4 (IN)
unnamed: D179.2 (O), D180.4 (IN)
unnamed: D180.2 (O), D181.4 (IN)
unnamed: D181.2 (O), D182.4 (IN)
unnamed: D182.2 (O), D183.4 (IN)
unnamed: D183.2 (O), D184.4 (IN)
unnamed: D184.2 (O), D185.4 (IN)
unnamed: D185.2 (O), D186.4 (IN)
unnamed: D186.2 (O), D187.4 (IN)
unnamed: D187.2 (O), D188.4 (IN)
unnamed: D188.2 (O), D189.4 (IN)
unnamed: D189.2 (O), D190.4 (IN)
unnamed: D190.2 (O), D191.4 (IN)
unnamed: D191.2 (O), D192.4 (IN)
unnamed: D192.2 (O), D224.4 (IN)
unnamed: D193.2 (O), D225.4 (IN)
unnamed: D193.4 (IN), D194.2 (O)
unnamed: D194.4 (IN), D195.2 (O)
unnamed: D195.4 (IN), D196.2 (O)
unnamed: D196.4 (IN), D197.2 (O)
unnamed: D197.4 (IN), D198.2 (O)
unnamed: D198.4 (IN), D199.2 (O)
unnamed: D199.4 (IN), D200.2 (O)
unnamed: D200.4 (IN), D201.2 (O)
unnamed: D201.4 (IN), D202.2 (O)
unnamed: D202.4 (IN), D203.2 (O)
unnamed: D203.4 (IN), D204.2 (O)
unnamed: D204.4 (IN), D205.2 (O)
unnamed: D205.4 (IN), D206.2 (O)
unnamed: D206.4 (IN), D207.2 (O)
unnamed: D207.4 (IN), D208.2 (O)
unnamed: D208.4 (IN), D209.2 (O)
unnamed: D209.4 (IN), D210.2 (O)
unnamed: D210.4 (IN), D211.2 (O)
unnamed: D211.4 (IN), D212.2 (O)
unnamed: D212.4 (IN), D213.2 (O)
unnamed: D213.4 (IN), D214.2 (O)
unnamed: D214.4 (IN), D215.2 (O)
unnamed: D215.4 (IN), D216.2 (O)
unnamed: D216.4 (IN), D217.2 (O)
unnamed: D217.4 (IN), D218.2 (O)
unnamed: D218.4 (IN), D219.2 (O)
unnamed: D219.4 (IN), D220.2 (O)
unnamed: D220.4 (IN), D221.2 (O)
unnamed: D221.4 (IN), D222.2 (O)
unnamed: D222.4 (IN), D223.2 (O)
unnamed: D223.4 (IN), D224.2 (O)
unnamed: D225.2 (O), D226.4 (IN)
unnamed: D226.2 (O), D227.4 (IN)
unnamed: D227.2 (O), D228.4 (IN)
unnamed: D228.2 (O), D229.4 (IN)
unnamed: D229.2 (O), D230.4 (IN)
unnamed: D230.2 (O), D231.4 (IN)
unnamed: D231.2 (O), D232.4 (IN)
unnamed: D232.2 (O), D233.4 (IN)
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

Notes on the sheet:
Auto Program
DTR
RTS
IO0

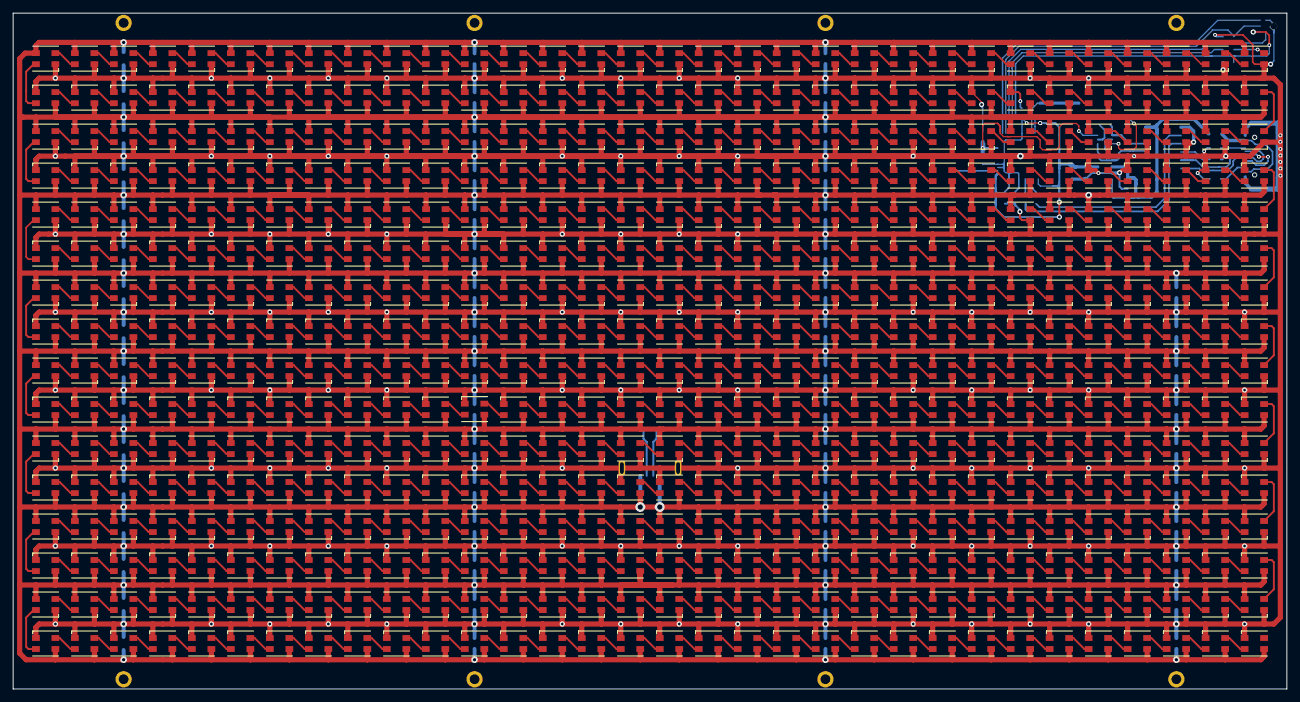
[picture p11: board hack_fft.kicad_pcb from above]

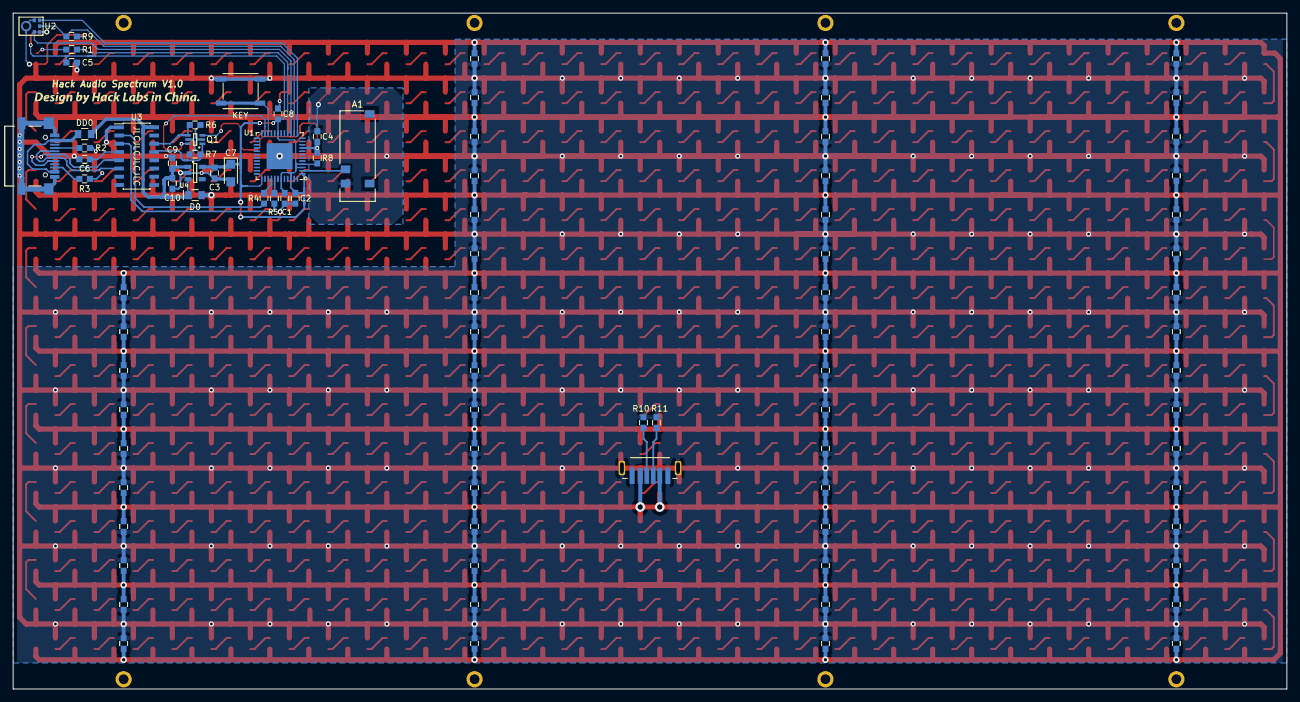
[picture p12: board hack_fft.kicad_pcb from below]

Board: 2 copper layers, 196.0 x 104.0 mm, 610 parts (90 on the bottom side), 540 nets.

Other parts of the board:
De: WS2812B; LED_WS2812B_3.5x3.5mm
P6, P6#2, P6#3, P6#4, P6#5, P6#6, P6#7, P6#8: CON_1; CON1

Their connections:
/V_RGB: De.1; also elsewhere on the board
GND: De.3; also elsewhere on the board
unnamed 58: De.4; also elsewhere on the board
unnamed 59: De.2; also elsewhere on the board

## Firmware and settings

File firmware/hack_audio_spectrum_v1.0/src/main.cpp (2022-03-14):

/*********************************************************************************************************
  HackLabs_Audio_Spectrum                                                                               
  ********************************************************************************************************
  Author: HACK实验室                                                                                     
  YouTubeID: HACK实验室, welcome to subscribe：https://www.youtube.com/channel/UCxFY1FcIYK9d7riTvIh6eiA                                                          
  Version 1.0 
  Hack_Audio_Spectrum is a free download and may be used, modified, evaluated and
  distributed without charge provided the user adheres to version hree of the GNU
  General Public License (GPL) and does not remove the copyright notice or this
  text. The GPL V3 text is available on the gnu.org web site

  作者：HACK实验室                                                                                        
  B站ID：HACK实验室  欢迎订阅：https://space.bilibili.com/395145107                                                                             
  微信公众号：HACK实验室，开源资料唯一发布点，定期分享开源硬件以及有价值的技术文章，欢迎关注.                        
  Version 1.0                                                                                           
  Hack_Audio_Spectrum 是一个完全开源的硬件项目，允许用户免费下载使用，但需遵守GPL V3开源协议，协议文本可在开源文件根目录或gnu.org网站上获得.  

  *如果你想调节LED亮度，请Ctrl+F搜索“FastLED.setBrightness(50)”，可将50改为0~255之间的任意数，但请注意电流，过亮可能会导致你的电源供电不足引起死机.
  *如果你想调节频谱的频响曲线，请到data.h中Ctrl+F搜索“fft_freq_boost[32]”，调节数组内的倍数来调节各个频段的增益.
  *如果你想调节频谱整体的增益，请到data.h中Ctrl+F搜索“gain=40”，更改这个值来适应你的音频环境.
*********************************************************************************************************/
#include "data.h"
#include <FastLED.h>
#include <LEDMatrix.h>
#include <LEDText.h>


#define DATA_PIN     27
#define BUTTON_PIN    2

#define MATRIX_WIDTH     32
#define MATRIX_HEIGHT    16
#define NUM_LEDS    (MATRIX_WIDTH * MATRIX_HEIGHT)

cLEDMatrix<-MATRIX_WIDTH, -MATRIX_HEIGHT, HORIZONTAL_ZIGZAG_MATRIX> leds;

uint8_t num_bands = 32;
uint8_t pattern= 0;
uint8_t color_timer = 0;

uint8_t bar_height[]  = {0,0,0,0,0,0,0,0,0,0,0,0,0,0,0,0,0,0,0,0,0,0,0,0,0,0,0,0,0,0,0,0};
uint8_t peak_height[] = {0,0,0,0,0,0,0,0,0,0,0,0,0,0,0,0,0,0,0,0,0,0,0,0,0,0,0,0,0,0,0,0};
uint8_t prev_fft_value[] = {0,0,0,0,0,0,0,0,0,0,0,0,0,0,0,0,0,0,0,0,0,0,0,0,0,0,0,0,0,0,0,0};

// Color Palette
DEFINE_GRADIENT_PALETTE(green_to_red) {
  0,   173,   255,    47,    //green
127,   255,   218,     0,    //yellow
255,   231,     0,     0 };  //red
DEFINE_GRADIENT_PALETTE(purple_to_blue) {
  0,   141,     0,   100,    //purple
127,   255,   192,     0,    //yellow
255,     0,     5,   255 };  //blue
DEFINE_GRADIENT_PALETTE(red_to_mistyrose) {
  0,   255,   228,   225,    //MistyRose
 64,   255,    69,     0,    //OrangeRed
127,   255,     0,     0,    //red
128,   255,     0,     0,    //red
192,   255,    69,     0,    //OrangeRed
255,   255,   228,   225 };  //MistyRose
CRGBPalette16 green_red_palette = green_to_red;
CRGBPalette16 purple_blue_palette = purple_to_blue;
CRGBPalette16 red_mistyrose_palette = red_to_mistyrose;
// end Color Palette

// bars patterns
void green_red_bars(int band, int bar) {
  for (int y = 0; y < bar; y++) {
    leds(band,y) = ColorFromPalette(green_red_palette, y * (255 / bar));
  }
}
void rainbow_bars(uint8_t band, uint8_t bar) {
  for (int y = 0; y <= bar; y++) {
    leds(band,y) = CHSV( (band*(255/num_bands)), 255, 255);
  }
}
void half_rainbow_bars(uint8_t band, uint8_t bar) {
  if ((band%2)==0){
    for (int y = 0; y <= bar; y++) {
    leds(band,y) = CHSV( (band*(255/num_bands)), 255, 255);
    }
  }
}
void center_bars(int band, int bar) {
  if (bar % 2 == 0) bar--;
  int y_start = ((MATRIX_HEIGHT - bar) / 2 );
  for (int y = y_start; y <= (y_start + bar); y++) {
    int color_index = constrain((y - y_start) * (255 / bar), 0, 255);
    leds(band,y) = ColorFromPalette(red_mistyrose_palette, color_index);
  }
}
void changing_bars(int band, int bar) {
  for (int y = 0; y < bar; y++) {
    leds(band,y) = CHSV(y * (255 / MATRIX_HEIGHT) + color_timer, 255, 255); 
  }
}// end bars patterns

// peaks patterns
void yellow_white_peak(int band) {
  leds(band, (int)peak_height[band]) = CRGB::White;
  if (peak_height[band] > 0) 
    leds(band,0) = CRGB::GreenYellow;
}
void white_peak(int band) {
  leds(band, (int)peak_height[band]) = CRGB::White;
}
void half_white_peak(int band) {
  if ((band%2)==0){
    leds(band, (int)peak_height[band]) = CRGB::White;
  }
}
void changing_peak(int band) {
  leds(band,(int)peak_height[band]) = ColorFromPalette(purple_blue_palette, peak_height[band] * (255 / MATRIX_HEIGHT));
}// end peaks patterns


// the setup function runs once when you press reset or power the board
void setup() {

  FastLED.addLeds<WS2812B, DATA_PIN, GRB>(leds[0], NUM_LEDS);
  FastLED.setBrightness(50);  //0~255
  Serial.begin(115200);
  pinMode(BUTTON_PIN, INPUT_PULLUP); //Set the button pin pull-up input mode
  audio_receive();

}// end setup 

// the loop function runs over and over again forever
void loop() {

  FastLED.clear();
  
  for (int i = 0; i < 32; i=i+1) {
    uint8_t fft_value;
    fft_value = fft_result[i];
    fft_value = ((prev_fft_value[i] * 3) + fft_value) / 4;   
    bar_height[i] = fft_value / (255 / (MATRIX_HEIGHT-1));       // scale bar height
    if (bar_height[i] > peak_height[i])                          // peak up
      peak_height[i] = min((MATRIX_HEIGHT-1), (int)bar_height[i]);
    prev_fft_value[i] = fft_value;        
  }

  for (int band = 0; band < num_bands; band++) {

    // Draw bars
    switch (pattern) {
      case 0:
        green_red_bars(band, bar_height[band]);
        break;
      case 1:
        rainbow_bars(band, bar_height[band]);
        break;
      case 2:
        half_rainbow_bars(band, bar_height[band]);
        break;
      case 3:
        center_bars(band, bar_height[band]);
        break;
      case 4:
        changing_bars(band, bar_height[band]);
        EVERY_N_MILLISECONDS(10) { color_timer++; }
        break;
    }
    // Draw peaks
    switch (pattern) {
      case 0:
        yellow_white_peak(band);
        break;
      case 1:
        white_peak(band);
        break;
      case 2:
        half_white_peak(band);
        break;
      case 3:
        // without peak
        break;
      case 4:
        changing_peak(band);
        break;
    }
  }

  EVERY_N_MILLISECONDS(100) {
    for (uint8_t band = 0; band < num_bands; band++)
      if (peak_height[band] > 0) peak_height[band] -= 1;
  }

  FastLED.show();
    
  if (digitalRead(BUTTON_PIN) == LOW) {
    delay(80);
    if (digitalRead(BUTTON_PIN) == LOW) {   
      pattern++;
      delay(80);
    }
  }
  if (pattern > 4) {
    pattern = 0;
  }

}// end loop

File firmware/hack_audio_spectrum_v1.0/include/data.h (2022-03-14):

/*********************************************************************************************************
  HackLabs_Audio_Spectrum                                                                               
  ********************************************************************************************************
  Author: HACK实验室                                                                                     
  YouTubeID: HACK实验室, welcome to subscribe：https://www.youtube.com/channel/UCxFY1FcIYK9d7riTvIh6eiA                                                          
  Version 1.0 
  Hack_Audio_Spectrum is a free download and may be used, modified, evaluated and
  distributed without charge provided the user adheres to version hree of the GNU
  General Public License (GPL) and does not remove the copyright notice or this
  text. The GPL V3 text is available on the gnu.org web site

  作者：HACK实验室                                                                                        
  B站ID：HACK实验室  欢迎订阅：https://space.bilibili.com/395145107                                                                             
  微信公众号：HACK实验室，开源资料唯一发布点，定期分享开源硬件以及有价值的技术文章，欢迎关注.                        
  Version 1.0                                                                                           
  Hack_Audio_Spectrum 是一个完全开源的硬件项目，允许用户免费下载使用，但需遵守GPL V3开源协议，协议文本可在开源文件根目录或gnu.org网站上获得.  
*********************************************************************************************************/

#include <arduinoFFT.h>
#include <driver/i2s.h>


#define I2S_WS    33
#define I2S_SD    25
#define I2S_SCK   26

const i2s_port_t I2S_PORT = I2S_NUM_0;
const int SAMPLE_BLOCK = 64;
const int SAMPLE_FREQ = 10240;

int gain=40;  //adjust it to set the gain   
uint16_t audio_data;                            

const uint16_t samples = 512;
unsigned int sampling_period_us;
unsigned long microseconds;

double vReal[samples];
double vImag[samples];
double fft_bin[samples];

double fft_data[32];
int fft_result[32]; 

//adjust single frequency curves.
double fft_freq_boost[32] = {1.02,1.03,1.04,1.06,1.08,1.10,1.10,1.11,1.12,1.13,1.15,1.16,1.17,1.18,1.20,1.21,1.30,1.51,2.11,2.22,3.25,3.26,3.52,3.55,4.22,4.24,5.52,5.55,6.53,6.55,8.82,8.88};

TaskHandle_t fft_task;

arduinoFFT FFT = arduinoFFT( vReal, vImag, samples, SAMPLE_FREQ);

double fft_add( int from, int to) {
  int i = from;
  double result = 0;
  while ( i <= to) {
    result += fft_bin[i++];
  }
  return result;
}

void fft_code( void * parameter) {

  for(;;) {

    delay(1);          

    microseconds = micros();

    for(int i=0; i<samples; i++) {
      int32_t digitalSample = 0;
      int bytes_read = i2s_pop_sample(I2S_PORT, (char *)&digitalSample, portMAX_DELAY); // no timeout
      if (bytes_read > 0) {
        audio_data = abs(digitalSample >> 16);
      }
      vReal[i] = audio_data; 
      vImag[i] = 0;
      microseconds += sampling_period_us;
    }

    FFT.Windowing( FFT_WIN_TYP_HAMMING, FFT_FORWARD ); 
    FFT.Compute( FFT_FORWARD ); 
    FFT.ComplexToMagnitude(); 

    for (int i = 0; i < samples; i++) {   
      double t = 0.0;
      t = abs(vReal[i]);
      t = t / 16.0;    
      fft_bin[i] = t;
    }

    fft_data[0]  = (fft_add(3,4))/2;       // 60-100Hz
    fft_data[1]  = (fft_add(4,5))/2;       // 80-120Hz
    fft_data[2]  = (fft_add(5,6))/2;       // 100-140Hz
    fft_data[3]  = (fft_add(6,7))/2;       // 120-160Hz
    fft_data[4]  = (fft_add(7,8))/2;       // 140-180Hz
    fft_data[5]  = (fft_add(8,9))/2;       // 160-200Hz
    fft_data[6]  = (fft_add(9,10))/2;      // 180-220Hz
    fft_data[7]  = (fft_add(10,11))/2;     // 200-240Hz
    fft_data[8]  = (fft_add(11,12))/2;     // 220-260Hz
    fft_data[9]  = (fft_add(12,13))/2;     // 240-280Hz
    fft_data[10] = (fft_add(13,14))/2;     // 260-300Hz
    fft_data[11] = (fft_add(14,16))/3;     // 280-340Hz
    fft_data[12] = (fft_add(16,18))/3;     // 320-380Hz
    fft_data[13] = (fft_add(18,20))/3;     // 360-420Hz
    fft_data[14] = (fft_add(20,24))/5;     // 400-500Hz
    fft_data[15] = (fft_add(24,28))/5;     // 480-580Hz
    fft_data[16] = (fft_add(28,32))/5;     // 560-660Hz
    fft_data[17] = (fft_add(32,36))/5;     // 640-740Hz
    fft_data[18] = (fft_add(36,42))/7;     // 720-860Hz
    fft_data[19] = (fft_add(42,48))/7;     // 840-980Hz
    fft_data[20] = (fft_add(48,56))/9;     // 960-1140Hz
    fft_data[21] = (fft_add(56,64))/9;     // 1120-1300Hz
    fft_data[22] = (fft_add(64,74))/11;    // 1280-1500Hz
    fft_data[23] = (fft_add(74,84))/11;    // 1480-1700Hz
    fft_data[24] = (fft_add(84,97))/14;    // 1680-1960Hz
    fft_data[25] = (fft_add(97,110))/14;   // 1940-2240Hz
    fft_data[26] = (fft_add(110,128))/19;  // 2200-2580Hz
    fft_data[27] = (fft_add(128,146))/19;  // 2560-2940Hz
    fft_data[28] = (fft_add(146,170))/25;  // 2920-3420Hz
    fft_data[29] = (fft_add(170,194))/25;  // 3400-3900Hz
    fft_data[30] = (fft_add(194,224))/31;  // 3880-4500Hz
    fft_data[31] = (fft_add(224,255))/32;  // 4520-5120Hz

    //adjust single frequency curves.
    for (int i=0; i < 32; i++) {
      fft_data[i] = fft_data[i] * fft_freq_boost[i];
    }

    //adjust overall frequency curves.
    for (int i=0; i < 32; i++) {
      fft_data[i] = fft_data[i] * gain / 50;
    }

    //constraint function
    for (int i=0; i < 32; i++) {
      fft_result[i] = constrain((int)fft_data[i],0,255);
    }
  }
}

void audio_receive() {
    
  esp_err_t err;
  const i2s_config_t i2s_config = {
    .mode = i2s_mode_t(I2S_MODE_MASTER | I2S_MODE_RX), 
    .sample_rate = SAMPLE_FREQ * 2,                       // 10240*2=20480Hz
    .bits_per_sample = I2S_BITS_PER_SAMPLE_32BIT, 
    .channel_format = I2S_CHANNEL_FMT_ONLY_LEFT,  
    .communication_format = i2s_comm_format_t(I2S_COMM_FORMAT_I2S | I2S_COMM_FORMAT_I2S_MSB),
    .intr_alloc_flags = ESP_INTR_FLAG_LEVEL1,
    .dma_buf_count = 8, 
    .dma_buf_len = SAMPLE_BLOCK
  };

  const i2s_pin_config_t pin_config = {
    .bck_io_num = I2S_SCK,
    .ws_io_num = I2S_WS,
    .data_out_num = -1, 
    .data_in_num = I2S_SD 
  };
  
  err = i2s_driver_install(I2S_PORT, &i2s_config, 0, NULL);
  if (err != ESP_OK) {
    Serial.printf("Failed installing driver: %d\n", err);
    while (true);
  }
  err = i2s_set_pin(I2S_PORT, &pin_config);
  if (err != ESP_OK) {
    Serial.printf("Failed setting pin: %d\n", err);
    while (true);
  }
  Serial.println("I2S driver installed.");
  delay(100);
  
  sampling_period_us = round(1000000*(1.0/SAMPLE_FREQ));
  
  xTaskCreatePinnedToCore(
        fft_code,                    //Task function
        "FFT",                       //Task name
        10000,                       //Task stack size(units:byte)
        NULL,                        //Parameters passed to the task function
        1,                           //Task priority
        &fft_task,                   //Task handle
        0);                          //Specifies the core to run the task
}
